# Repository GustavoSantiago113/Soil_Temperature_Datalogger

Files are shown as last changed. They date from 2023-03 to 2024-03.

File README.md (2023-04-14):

# Soil Temperature Data logger

## List of Contents

1. [Objective](#objective)
2. [Data logger working flow](#data-logger-working-flow)
3. [List of Materials](#list-of-materials)
4. [Circuit Boards](#circuit-boards)
5. [Algorithm](#algorithm)
6. [3D Files](#3d-files)
7. [Future works](#future-works)

---

## Objective
Develop a data logger to collect soil temperature in a growth chamber using Arduino e temperature sensors. It works with batteries and save the sensor data along with the date and time into a microSD card.

---

## Data logger working flow
Into a loop that repeats every 3 hours, the sensors get the temperature value (on a delay of 1 second between each sensor reading) and store into a .txt file. The .txt file is in a microSD card. Along with the sensors' reading data, the date and time is also sent to the .txt file.

The final .txt file is a line per reading with date, hour and sensors' data, all separated by commas.

---

## List of Materials

| Material | Amount | Description | Price (USD) |
|--- | --- | --- | --- |
| Arduino Uno | 1 | This is the brain, where the sensors will be plugged in and information passed to the SD card | 10 |
| Sensors ds18b20 | 24 | They will read the soil temperature | 52.8 |
| RTC Watch + Coin Battery | 1 | Provides the minute/hour/date/month/year | 3 |
| Power supply adaptor | 1 | Power supply | 7.5 |
| Arduino Enclosure | 1 | To protect everything | 12 |
| microSD card module | 1 | The device that will transfer the information to the microSD card | 5.5 |
| microSD card 32 GB | 1 | Where the data will be stored | 3.6 |
| PCBs, soldering, male and female pins | X | Connect the electronic parts of sensors and other modules to the Arduino | 2 |
| |  | **Total** | 96.4 |

<br>

---

## Circuit Boards
Two circuit boards were made:
1. Connection of all the sensors in parallel. This one was left outside to not open 24 holes in the enclosure. Just 3 wires (VCC, ground and data) were passed through the enclosure. They were soldered in the board according to the sensors' terminals;
2. Arduino shield. This board was designed to be connected to the Arduino via male pins and connect with the other modules and the sensors' board with female pins. 

From the images bellow, circuit boards were designed in LibreCAD program. The files containing the circuit boards' draws are in the folder Circuit, with the name PCB.dxf.

**<center>Sensors' circuit board schema</center>**

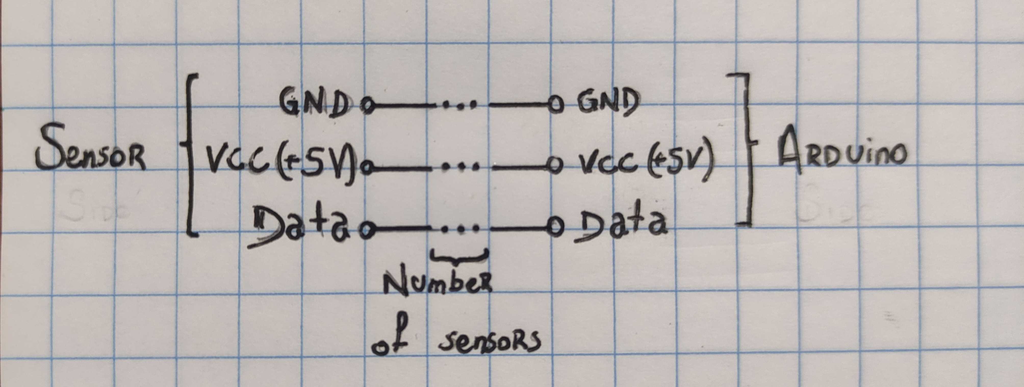
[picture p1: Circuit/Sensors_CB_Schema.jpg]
Sensors' circuit board schema


**<center>**Arduino shield schema**</center>**

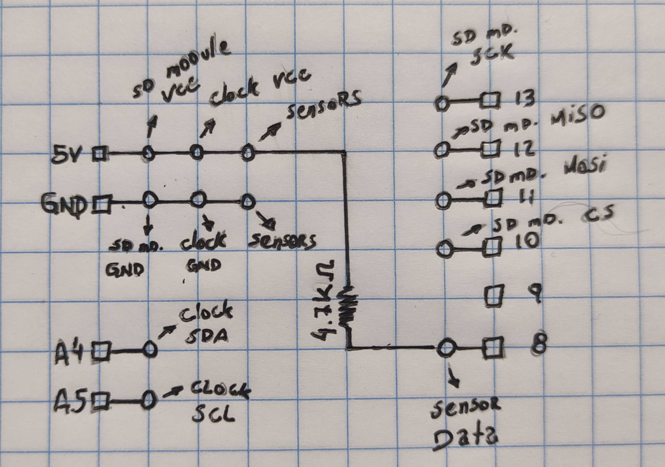
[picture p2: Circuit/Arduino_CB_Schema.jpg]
Arduino circuit board schema


---

## Algorithm
The algorithm was made in C++ using Arduino IDE, since it is for Arduino. It is located in the Algorithm folder. The algorithm is structured as followed:
- Inclusion of libraries for SD card, RTC clock, temperature sensor and to put Arduino to sleep;
- Declaration of variables;
- Setup, that only runs once when the Arduino is restarted. On this function, i) the sensors are initialized, counted, located and displayed in the screen the hexadecimal address of each one; ii) the clock is initialized and adjusted only once; iii) initialize the microSD card;
- Loop, that keep running. On this function, i) the date and time information is stored in a variable, ii) the temperatures data are gotten, iii) the .txt file is opened, iv) date and time are printed in the .txt file, v) in a loop, the temperatures of the 24 sensors are obtained and printed in the .txt file with a delay of 1s between each reading, vi) a new line is printed in the .txt file, and it is closed and lastly, vii) the Arduino sleeps for the amount of period selected;
- Function to print the hexadecimal address of each found sensor.

---

## 3D Files
The 3D files were designed by own author in Fusion360 and printed in a Creality filament 3D printer. All the STL files are in the folder "3D Files". They are holders to stick in place the Arduino, sensors' board, RTC and microSD Card modules.

---

## Future works

The future work is to connect the data loggers to the internet and upload the data to the cloud. With the data into an online database, there is no need of removing and reading the microSD card and inserting automatic analysis and chart plotting.

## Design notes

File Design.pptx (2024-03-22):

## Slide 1

Data Visualization Hub

XX

Block 1

XX

Block 2

XX

Block 3

XX

Block 4

By block

Last Readings

Block 1

Block 2

Block 3

Block 4

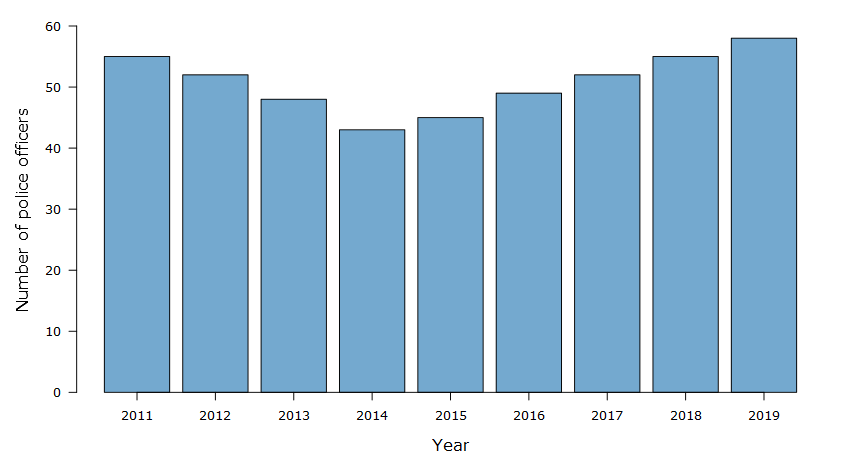
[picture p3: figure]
5.2 Bar chart

Mean of blocks

By blocks

Block 1

Block 2

Block 3

Block 4

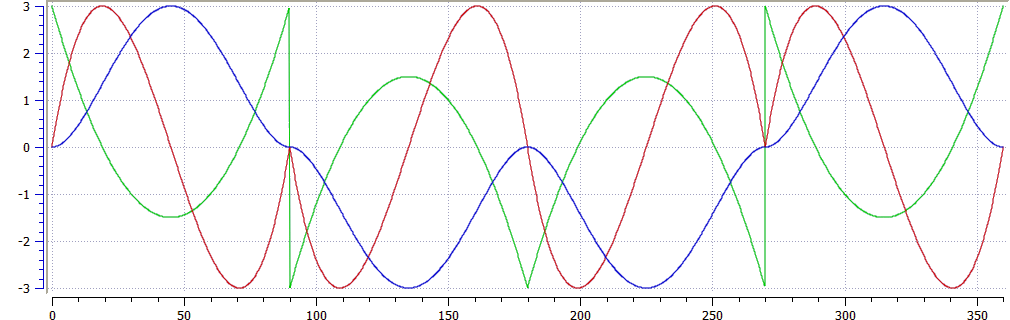
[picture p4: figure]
Curves Graph

Temperature curves

Mean of blocks

Day

Week

Year

Day

Week

Year

Download the data

Download

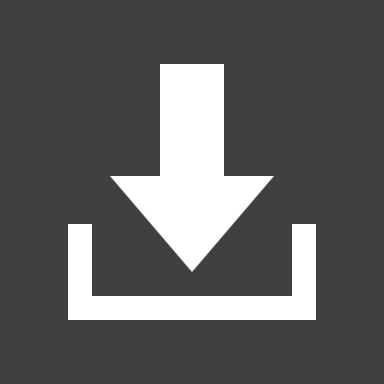
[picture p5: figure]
Download

This tool was developed by the Ciampitti Lab Group

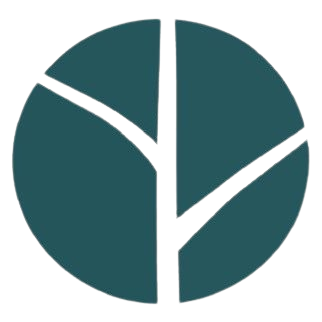
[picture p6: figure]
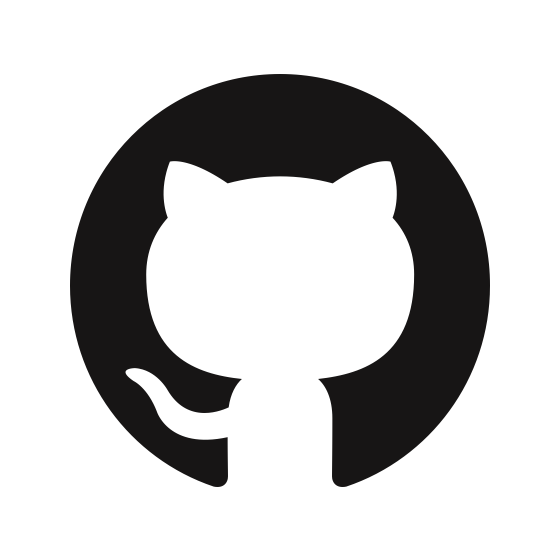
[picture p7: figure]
GitHub Logos and Usage · GitHub

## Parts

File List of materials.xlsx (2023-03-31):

Data Logger materials and description
Materials | Amount | Description
Arduino Uno | 1 | This is the brain, where the sensors will be plugged in and information passed to the SD card
Sensors | 24 | They will read the information of the soil
RTC Watch + Coin Battery | 1 | Will give the minute/hour/date/month/year to be stored
Power supply adaptor | 1 | The power supply
Arduino Enclosure | 1 | To protect everything
SD Card module | 1 | The device that will pass the information to the SD card
Micro SD 32GB | 1 | Where the data will be stored

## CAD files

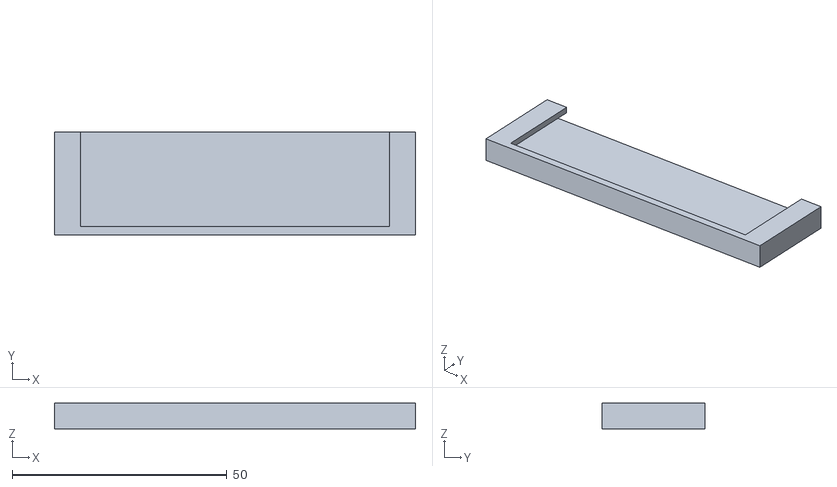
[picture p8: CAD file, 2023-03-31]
3D files/Sensors Holder.stl
84.0 x 24.0 x 6.00

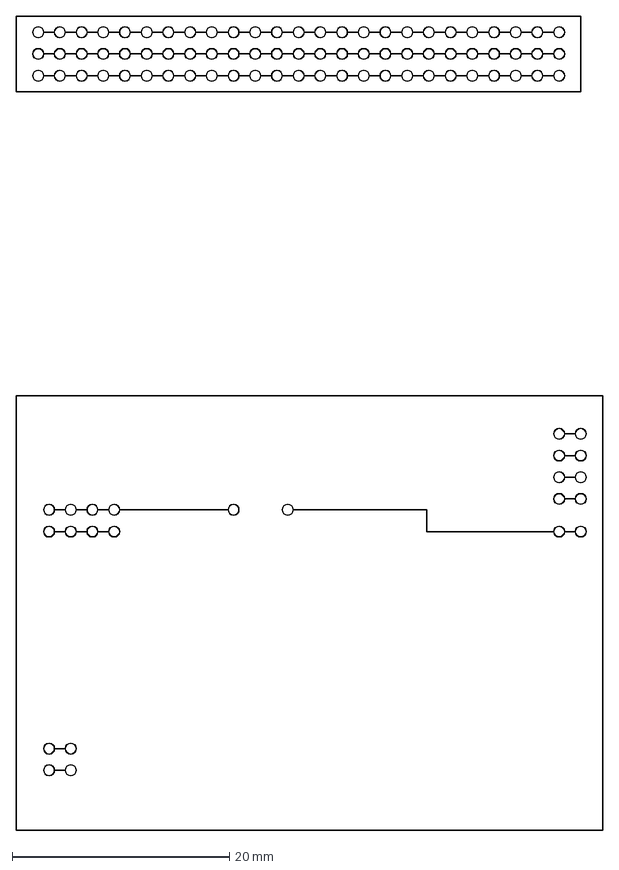
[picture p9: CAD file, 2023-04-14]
Circuit/#PCBs.dxf
54.0 x 75.0 mm

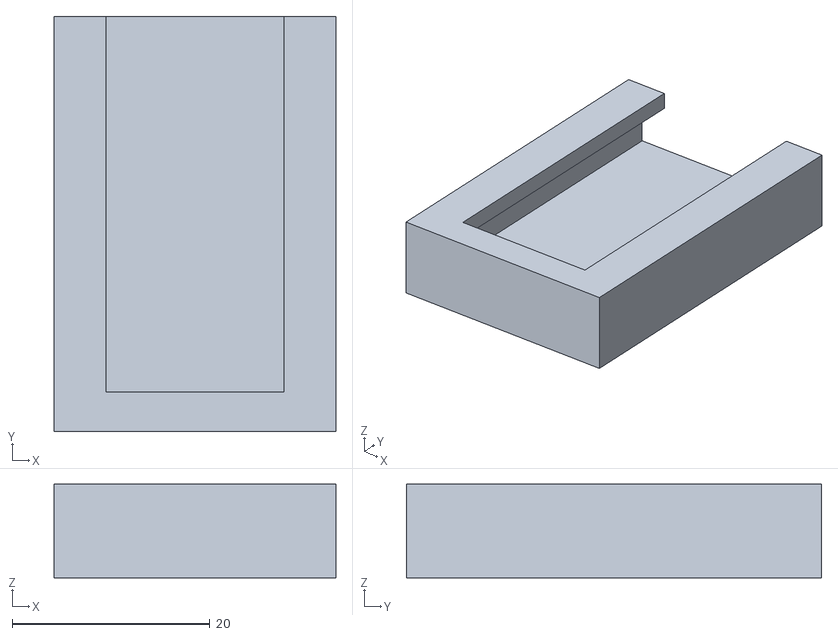
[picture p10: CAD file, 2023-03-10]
3D files/SDCard Holder.stl
28.5 x 42.0 x 9.50

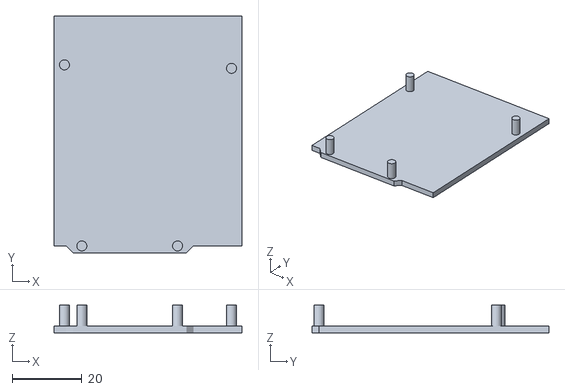
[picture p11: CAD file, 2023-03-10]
3D files/Arduino Uno Holder.stl
54.0 x 68.0 x 8.00

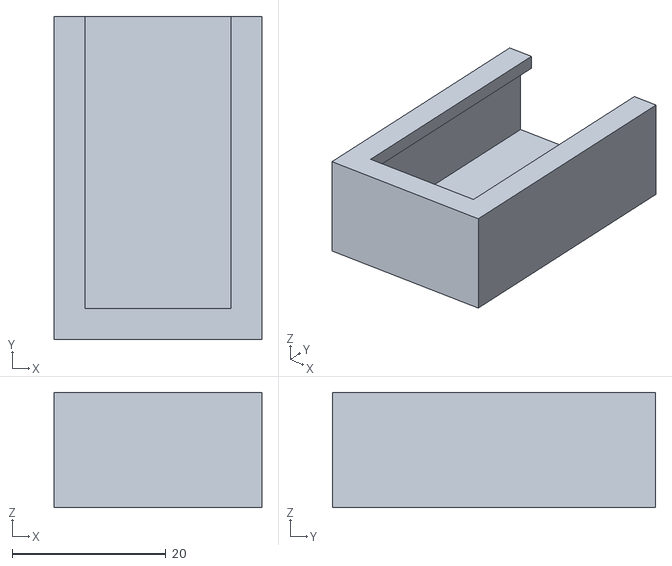
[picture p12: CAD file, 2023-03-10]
3D files/RTC Holder.stl
27.0 x 42.0 x 15.0

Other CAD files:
Circuit/PCBs.dxf

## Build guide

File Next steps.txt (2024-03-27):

* Encontrar uma forma de validar;

* Escrever;

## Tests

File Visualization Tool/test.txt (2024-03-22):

Group,Device,Reading,Date,Time
1,0,20.75,21/3/2024,16/23
1,1,21.12,21/3/2024,16/23
1,3,21.75,21/3/2024,16/23
1,4,20.44,21/3/2024,16/23
1,5,20.44,21/3/2024,16/23
1,6,20.94,21/3/2024,16/23
1,7,20.81,21/3/2024,16/23
1,8,20.87,21/3/2024,16/23
1,9,20.56,21/3/2024,16/23
1,10,20.81,21/3/2024,16/23
1,11,21.12,21/3/2024,16/23
1,12,20.19,21/3/2024,16/23
1,13,20.69,21/3/2024,16/23
1,14,21.25,21/3/2024,16/23
1,15,21.06,21/3/2024,16/23
1,16,20.50,21/3/2024,16/23
1,17,21.12,21/3/2024,16/23
1,18,20.31,21/3/2024,16/23
1,19,20.69,21/3/2024,16/23
1,20,20.75,21/3/2024,16/23
1,21,20.44,21/3/2024,16/23
1,22,20.25,21/3/2024,16/23
1,0,20.75,21/3/2024,16/24
1,1,21.12,21/3/2024,16/24
1,2,21.12,21/3/2024,16/24
1,3,21.81,21/3/2024,16/24
1,4,20.44,21/3/2024,16/24
1,5,20.37,21/3/2024,16/24
1,6,20.94,21/3/2024,16/24
1,7,20.87,21/3/2024,16/24
1,8,20.87,21/3/2024,16/24
1,9,20.50,21/3/2024,16/24
1,10,20.81,21/3/2024,16/24
1,11,21.12,21/3/2024,16/24
1,12,20.06,21/3/2024,16/24
1,13,20.69,21/3/2024,16/24
1,14,21.25,21/3/2024,16/24
1,15,21.06,21/3/2024,16/24
1,16,20.50,21/3/2024,16/24
1,17,21.12,21/3/2024,16/24
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
,,,,
1,8,20.94,21/3/2024,16/28
1,9,20.94,21/3/2024,16/28
1,10,20.87,21/3/2024,16/28
1,11,20.56,21/3/2024,16/28
1,12,19.94,21/3/2024,16/28
1,13,20.62,21/3/2024,16/28
1,14,20.81,21/3/2024,16/28
1,15,20.44,21/3/2024,16/28
1,16,20.19,21/3/2024,16/28
1,17,20.44,21/3/2024,16/28
1,18,20.06,21/3/2024,16/28
1,19,20.31,21/3/2024,16/28
1,20,20.12,21/3/2024,16/28
1,21,20.87,21/3/2024,16/28
1,0,20.69,21/3/2024,16/30
1,1,20.56,21/3/2024,16/30
1,2,20.69,21/3/2024,16/30
1,3,21.37,21/3/2024,16/30
1,4,19.87,21/3/2024,16/30
1,5,20.87,21/3/2024,16/30
1,6,20.50,21/3/2024,16/30
1,7,20.44,21/3/2024,16/30
1,8,20.94,21/3/2024,16/30
1,9,21.00,21/3/2024,16/30
1,10,20.94,21/3/2024,16/30
1,11,20.56,21/3/2024,16/30
1,12,20.00,21/3/2024,16/30
1,13,20.62,21/3/2024,16/30
1,14,37.63,21/3/2024,16/30
1,15,20.44,21/3/2024,16/30
1,16,20.19,21/3/2024,16/30
1,17,20.50,21/3/2024,16/30
1,18,20.12,21/3/2024,16/30
1,19,20.37,21/3/2024,16/30
1,20,20.12,21/3/2024,16/30
1,21,20.81,21/3/2024,16/30
1,22,20.50,21/3/2024,16/30
1,0,20.69,21/3/2024,16/31
1,1,20.56,21/3/2024,16/31
1,2,20.62,21/3/2024,16/31
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

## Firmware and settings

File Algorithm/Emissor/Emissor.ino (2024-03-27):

// Author: Gustavo Nocera Santiago

// Including Libraries
#include <Wire.h>
//#include <SD.h> // For SD Card
//#include <SPI.h> // For SD Card
#include <RTClib.h> // For RTC Clock
#include <OneWire.h> // For Temperature Sensor
#include <DallasTemperature.h> // For Temperature Sensor
#include <LowPower.h> // Put Arduino to sleep and save energy
#include <LoRa.h> // LoRa usage

// Lora pins
#define ss 10
#define rst 9
#define dio0 2

// Device ID
int ID = 1;

// Variables for RTC
RTC_DS3231 rtc;

// Variables for Temp sensors
const int ONE_WIRE_BUS = 4;

// Setup a oneWire instance to communicate with any OneWire device
OneWire oneWire(ONE_WIRE_BUS);

// Pass oneWire reference to DallasTemperature library
DallasTemperature sensors(&oneWire);

// Number of temperature devices you are using
int numberOfDevices; 

// Define the maximum number of sensors
#define MAX_SENSORS 4 

// We'll use this variable to store a found device address
DeviceAddress tempDeviceAddress[MAX_SENSORS];
int foundSensors = 0;

void setup() {

  Serial.begin(9600);

  // Clock
  if (! rtc.begin())
  {
    Serial.println("Clock module not found!");
    while(1);
    
  }
  //rtc.adjust(DateTime(F(__DATE__), F(__TIME__))); //Upload code once with this line uncommented so the clock is adjusted, then coment this line and upload again
  LoRa.setPins(ss, rst, dio0);

  // LoRa begin
  if (LoRa.begin(915E6)) {
    Serial.println("Starting LoRa success!");
    delay(500);
  }else{
    Serial.println("Starting LoRa Failed!");
  }
  LoRa.setSyncWord(0xF3);

  // Sensors begin
  sensors.begin();

  // locate devices on the bus
  Serial.print("Locating devices...");

  // Grab a count of devices on the wire
  numberOfDevices = sensors.getDeviceCount();
  Serial.print("Found ");
  Serial.print(numberOfDevices, DEC);
  Serial.println(" devices.");
  
  while (foundSensors < MAX_SENSORS) {
    sensors.begin();
    numberOfDevices = sensors.getDeviceCount();

    for (int i = 0; i < numberOfDevices && foundSensors < MAX_SENSORS; i++) {
      if (sensors.getAddress(tempDeviceAddress[foundSensors], i)) {
        Serial.print("Found device ");
        Serial.print(foundSensors, DEC);
        Serial.print(" with address: ");
        printAddress(tempDeviceAddress[foundSensors]);
        Serial.println();
        foundSensors++; // Increment the counter for found sensors
      } else {
        Serial.print("Found ghost device at ");
        Serial.print(i, DEC);
        Serial.println(", but could not detect address. Check power and cabling");
      }
      
    }
    // If not all sensors are found, delay and then retry
    if (foundSensors < MAX_SENSORS) {
      Serial.println("Not all sensors found. Retrying in 5 seconds...");
      delay(5000);
      foundSensors = 0;
    }
  }
  
}

void loop() {
  
  // Clock
  DateTime fecha = rtc.now();

  // Send the command to get temperatures
  sensors.requestTemperatures();

  Serial.print(fecha.day());
  Serial.print("/");
  Serial.print(fecha.month());
  Serial.print("/");
  Serial.print(fecha.year());
  Serial.print(", ");
  Serial.print(fecha.hour());
  Serial.print(":");
  Serial.println(fecha.minute());
  
  // Loop through each device, print out temperature data
  for(int i=0; i < numberOfDevices && i < MAX_SENSORS; i++) {
    float tempC = sensors.getTempC(tempDeviceAddress[i]);
    Serial.print("Temperature for device: ");
    Serial.print(i,DEC);
    Serial.print(" - "); 
    Serial.println(tempC);
    sendPacket(i, tempC, fecha);
    delay(250);
  }

  
  
  for(int i = 0; i<= 15; i++) //Here (i<=5400) you insert the number of seconds divided by two (i.e. you want 1 minute, so 60/2=30)
  {
     LowPower.powerDown(SLEEP_2S, ADC_OFF, BOD_OFF);
  }

}

// function to print a device address
void printAddress(DeviceAddress deviceAddress) {
  for (uint8_t i = 0; i < 8; i++) {
    if (deviceAddress[i] < 16) Serial.print("0");
      Serial.print(deviceAddress[i], HEX);
  }
}

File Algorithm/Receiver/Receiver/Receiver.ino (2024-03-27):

// Author: Gustavo N. Santiago

//Libraries for LoRa
#include <SPI.h>
#include <LoRa.h>

// Libraries for microSD card
#include <SD.h>

//Libraries for OLED Display
#include <Wire.h>
#include <Adafruit_GFX.h>
#include <Adafruit_SSD1306.h>

//Libraries for WiFi and MongoDB
#include <ArduinoJson.h>
#include <WiFi.h>
#include <HTTPClient.h>
#include "secrets.h"

//Define the pins used by the LoRa transceiver module
#define SCLK 5
#define MISO 19
#define MOSI 27
#define CS 18
#define RST 23
#define DIO0 26

// SD SPI pins
#define SD_CS 13
#define SD_SCK 14
#define SD_MOSI 15
#define SD_MISO 2

//OLED pins
#define OLED_SDA 21
#define OLED_SCL 22 
#define SCREEN_WIDTH 128 // OLED display width, in pixels
#define SCREEN_HEIGHT 64 // OLED display height, in pixels
Adafruit_SSD1306 display(SCREEN_WIDTH, SCREEN_HEIGHT, &Wire, OLED_RST);

// For SD card
File myFile;
SPIClass sd_spi(HSPI);

// Setting up a variable to store data from LoRa
String LoRaData;

// Monitore sending data to cloud
int httpResponseCode;

// Minimizing number of requests
#define MAX_ENTRIES 4 // Number of sensors
int entryCount = 0;
struct Reading {
  String device;
  String reading;
};
Reading readings[MAX_ENTRIES];
DynamicJsonDocument doc(1024);

void setup() { 

  // Initialize Serial Monitor
  Serial.begin(115200);

  // Initialize OLED
  Wire.begin(OLED_SDA, OLED_SCL);
  if(!display.begin(SSD1306_SWITCHCAPVCC, 0x3c, false, false)) { // Address 0x3C for 128x32
    Serial.println(F("SSD1306 allocation failed"));
    for(;;); // Don't proceed, loop forever
  }

  display.clearDisplay();
  display.setTextColor(WHITE);
  display.display();

  Serial.println("LoRa Receiver Test");
  
  //SPI LoRa pins
  SPI.begin(SCLK, MISO, MOSI, CS);
  LoRa.setPins(CS, RST, DIO0);

  //Initialize LoRa
  if (!LoRa.begin(915E6)) {
    Serial.println("Starting LoRa failed!");
    while (1);
  }

  //Set the specific communication between devices
  LoRa.setSyncWord(0xF3);

  Serial.println("LoRa Initializing OK!");
  display.setCursor(0,10);
  display.println("LoRa Initializing OK!");
  display.display();

  // Initialize microSD card
  sd_spi.begin(SD_SCK, SD_MISO, SD_MOSI, SD_CS);

  if (SD.begin(SD_CS, sd_spi)) {
    display.clearDisplay();
    display.setCursor(0,10);
    display.println("Card initialized.");
    display.display();
    Serial.println("Card initialized.");
  }
  else{
    display.clearDisplay();
    display.setCursor(0,10);
    display.println("Card failed, or not present");
    display.display();
    Serial.println("Card failed, or not present");
    while(1);
  }

  // Connecting to internet
  WiFi.begin(ssid, password);
  while(WiFi.status() != WL_CONNECTED) {
    delay(500);
    Serial.println(".");
  }
  Serial.print("Connected to WiFi network with IP Address: ");
  Serial.println(WiFi.localIP());

}

void loop() {

  // Try to parse packet
  int packetSize = LoRa.parsePacket();

  String id;
  String device;
  String reading;
  String date;

  if (packetSize) {

    doc.clear();

    // Read packet
    while (LoRa.available()) {

      LoRaData = LoRa.readStringUntil(':');

      if(LoRaData.endsWith("ID"))
        id = LoRa.readStringUntil(',');
      if(LoRaData.endsWith("Device"))
        device = LoRa.readStringUntil(',');
      if(LoRaData.endsWith("Temperature"))
        reading = LoRa.readStringUntil(',');
      if(LoRaData.endsWith("DateTime"))
        date = LoRa.readStringUntil(',');

    }

    myFile = SD.open("/test.txt", FILE_APPEND);
    myFile.print(id);
    myFile.print(",");
    myFile.print(device);
    myFile.print(",");
    myFile.print(reading);
    myFile.print(",");
    myFile.print(date);
    myFile.println(",");
    myFile.close();

    Serial.println("Saved data to SD card.");

    // Print RSSI of packet
    int rssi = LoRa.packetRssi();

    //Parsing Data to JSON:
    doc["group"] = id;
    readings[entryCount].device = device;
    readings[entryCount].reading = reading;
    doc["dateTime"] = date;
    doc["LoRa RSSI"] = rssi;
    doc["Wifi RSSI"] = String(WiFi.RSSI());
    entryCount++;

    bool hasErrorReading = false;
    for (int i = 0; i < entryCount; i++) {
      if (readings[i].reading == "-127.00") {
        hasErrorReading = true;
        break; // Exit the loop early if an error reading is found
      }
    }

    if (entryCount == MAX_ENTRIES) {
      POSTData();
      entryCount = 0;
    }

    // Display information
    display.clearDisplay();
    display.setCursor(0,0);
    display.print("Received packet");

    display.setCursor(0,10);
    display.print("Group:");
    display.setCursor(40,10);
    display.print(id);

    display.setCursor(0,20);
    display.print("RSSI:");
    display.setCursor(50,20);
    display.print(rssi);

    display.setCursor(0,30);
    display.print("Response:");
    display.setCursor(60,30);
    if(httpResponseCode == 200){
      display.print("Sucess");
    }
    else{
      display.print("Error");
    }

    if(hasErrorReading == true){
      display.setCursor(0,40);
      display.print("Sensor reading error");
    }
    display.display();

  }

}

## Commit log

2023-03-31 Almost ending
    [Battery Holder.stl, List of materials.xlsx, Sensors Holder.stl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]
2023-04-14 Version 1 end
    [#PCBs.dxf, PCBs.dxf]
2024-03-22 Back-end visualization tool
    [file.csv, file.xlsx]
2024-03-25 Front and back end
    [file.csv]
2024-03-27 Sensors tracking
2024-03-27 Temperature in the y axis
